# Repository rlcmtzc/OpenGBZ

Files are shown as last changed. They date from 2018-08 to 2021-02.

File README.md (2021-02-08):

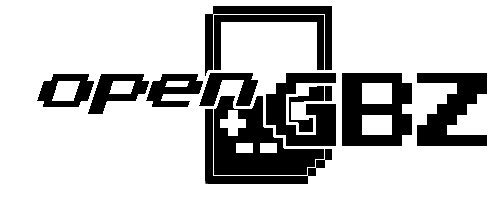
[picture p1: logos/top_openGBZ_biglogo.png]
openGBZ Logo
&emsp;&emsp;&emsp;&emsp;&emsp;&emsp;&emsp;&emsp;&emsp;&emsp;&emsp;
# OpenGBZ
This is an **OpenSource Gameboy Zero PCB Project**. It is intended to make your own custom Button PCB and change the design to your wishes.  
Your welcome to download the PCB files and use it for your own project. If you change anything on the design it would be great if you  
push your changes here so the project can grow and we can get some nice different designs and ideas. Feel also free to push other gameboyzero related PCBs if you want to share them. 

Please also add your changes to the [forum](https://www.sudomod.com/forum/viewtopic.php?f=42&t=6499) post so everybody can easily see the changes and features of the different designs. I will also add the different designes here in the Readme file (Can´t update all the time and immediately so in the forum should be the newest versions and of course in the different directories)  

## How to add your Design and what is needed:
In the different directories you find the different PCBs. If you want to push a design please add a new directory with a name for your designe and in there add a README.md where you can shortly describe the features of your PCB.  

This readme should at least include (See OSDMG0v1 and OSDMG0v2 as a template) :
* **Your name** (and on which board its based of)
* If you tested the Board and if it works
* if you have also a BOM-file for the needed components
* if used in a Build you can link the Build
* A description of the Features of the Board (also some Pictures would be nice)
* Additional Info to the Board if needed. (For example a tutorial how to use specific non self-describing parts pf the boards or also provide software if needed)
* Short description on how to use the board and a list of parts needed for the Board (if not included in the BOM file)  

In the same directory as the readme you should add the .sch and .brd files and gerbers. (You can also link to your project if it was created with an online editor just make sure everybody can get the files)  

You can also add your current work in progress files and ask others for ideas or feedback. If so mark your post as work in progress.  

## Overview of currently added projects:
Here is a short overview of the currently added projets to this repository pleas keep in mind that this part is not necessary up to date pleas look in the forum post or in the different directories for the newest designs.  

| Directory Name | Author Name | Tested | BOM-file | progress |
| :---:|:---:| :---:| :---: | :---:|
| OSDMGBASE | rlcmtzc12 | Yes | not needed| finished |
| OSDMG0v1 | rlcmtzc12 | Yes | Yes | finished |
| OSDMG0v2 | rlcmtzc12 | No | Yes | finished |
| GBPBASE by DerNuntius| DerNuntius | Yes | not needed| finished |
| OSDMG_Leonardo_Shield| rlcmtzc12 (correia5022´s idea)| No | not needed| finished |
## Terms of use
* **You can do everything with the files the only thing I would appreciate is not to use the designs and sell the PCBs this should stay a non-profit project.**
* **Please add the logo found in this directory and add it to your PCB so everybody can determ that this is part of this project**
* **If your design bases of another designe please reference the author**
* **Be sure your files are availible and the readme is present**  

This Project should be for makers who want to create their own projects or just to test something new and this should be a help to getting started. If I see that the terms of use won´t be followed (especially the selling of boards) I´m forced to take down the project or to find another (not that open and easy) way to share the project.  

---  

Feel free to give me feedback/improvements (Best way to get in contact with me is over the [forum](https://www.sudomod.com/forum/memberlist.php?mode=viewprofile&u=9560) just leave a pm)  
Also I´m not a nativ english sepaker so be gracious :D  
I´m looking forward too see your designs

## License
Shield: [][cc-by-sa]

This work is licensed under a
[Creative Commons Attribution-NonCommercial-ShareAlike 4.0 International License][cc-by-sa].

[][cc-by-sa]

[cc-by-sa]: https://creativecommons.org/licenses/by-nc-sa/4.0/
[cc-by-sa-image]: https://i.creativecommons.org/l/by-nc-sa/4.0/88x31.png
[cc-by-sa-shield]: https://img.shields.io/badge/License-CC%20BY--NC--SA%204.0-lightgrey.svg

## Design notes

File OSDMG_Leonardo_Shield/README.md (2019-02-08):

**Author:** rlcmtzc12 *(Based on correia5022 idea)*  
**Tested:** no  
**BOM-file:** not needed   
**Build:** /  

## Description:

This is a Shield like Projekt for the Leonardo/ Pro micro. There is place for a Pro Micro or Leonardo Board and a Battery input and a LED output. It can be also used the same liek the OSDMGBASE Board by just using the throughole pads (Bat and LED of course only works with an Arduino/Leonardo Board).
## Get Project:
The attached Eagle-files include everything.

## Images:

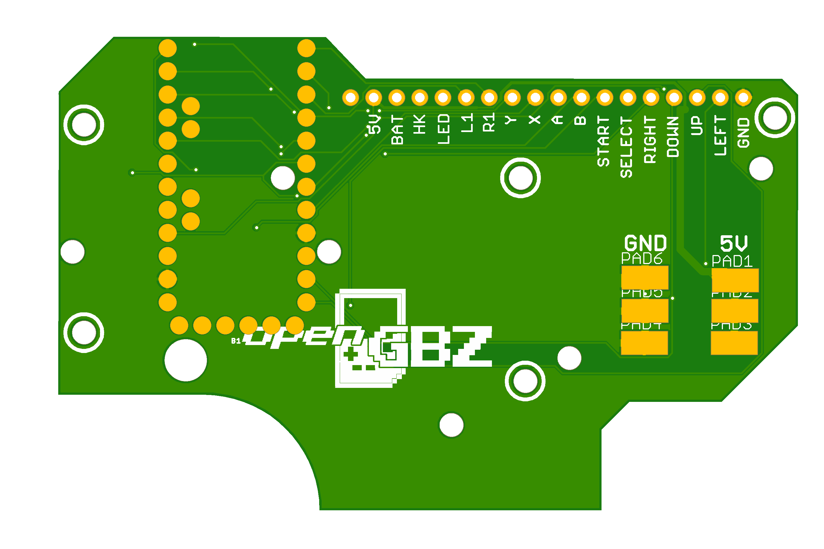
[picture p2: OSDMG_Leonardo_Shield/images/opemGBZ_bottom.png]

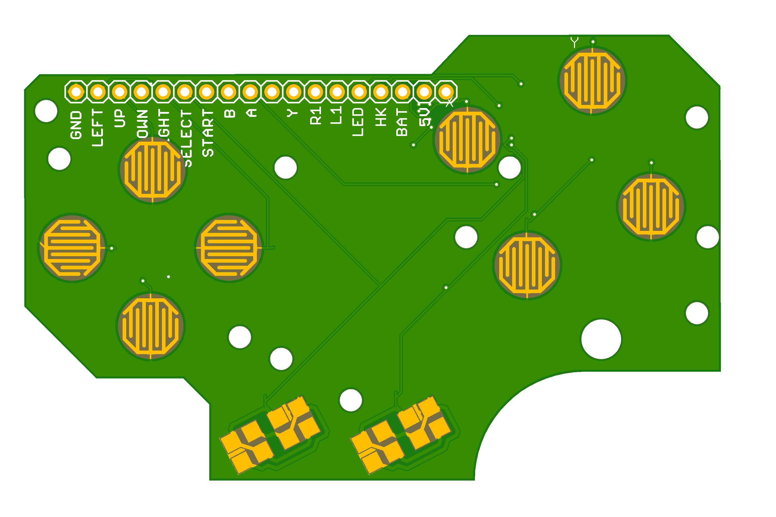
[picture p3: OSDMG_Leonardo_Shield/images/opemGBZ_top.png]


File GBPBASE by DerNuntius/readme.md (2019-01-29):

# First revision of the Gameboy Pocket PCB

**Author:** DerNuntius

**Tested:** Yes

**BOM-file:** unnecessary

**Build:** Later...

## Description:

It's a simple button PCB for the Gameboy Pocket. The PCB is perfect for projects with a Raspberry Pi or an Arduino to create an Arduboy clone.

## Get Project:
[Here](https://github.com/DerNuntius/Gameboy-Zero-Pocket-Button-PCB)

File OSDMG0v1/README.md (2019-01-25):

# First Version of my opensource DMG Board

**Author:** rlcmtzc12 *(Based on rlcmtzc12 design)*  
**Tested:** Yes and working  
**BOM-file:** Included  
**Build:** [Build](https://www.sudomod.com/forum/viewtopic.php?f=43&t=6388)

## Description:

This board has an integrated charging and Boost circuit. The Boost circuit is based on the MT3608 step up IC. (Datasheed found [here](https://www.olimex.com/Products/Breadboarding/BB-PWR-3608/resources/MT3608.pdf)) The outputvoltage is set to around 5.2 Volt. The Boost circuit can be switched on with a powerswitch. I have tested the boostcitcuit with 1,4 A which works fine but the IC gets a little bit warm. I also tested it with 2A which is the max outputcurrent from the Datasheed which works but the IC get really warm so I wouldnd suggest that. On 1 - 1,2A the IC isn´t even warm so it works perfectly fine in this range. The charging circuit of the Battery is based on TP4056 IC which can charge a single lithium-ion battery with up to 1A (Datasheed found [here](https://www.e-gizmo.net/oc/kits%20documents/TP4056-1A%20Li-ion%20Battery%20Charger/TP4056-1A%20Li-ion%20battery%20charger%20Manual.pdf)). Also I integrated the FS312G-F IC which protect the Battery from overcharge, overdischarge and overcurrent (Datasheed found [here](https://www.ic-fortune.com/upload/Download/FS312F-G-DS-12_EN.pdf)). The board will be charged with an usb type c connector. On the board is place for an standard PAM module which then connect to place for a volumewheel and the aux-port. On the front there are the standard buttons (Up, Down, Left, Right, Start, Select, A, B, X, Y)  

## Get Project:
[Here](https://easyeda.com/editor#id=|1b6bda1489604f5b8086fe82ce4b43ba|fd54b8f932f541aa9ddfa8aae15e51a3) you can edit and change the Project online. There are also the Altium and Eagle files.
## Images:




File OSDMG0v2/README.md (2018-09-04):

# Second Version of my opensource DMG Board

**Author:** rlcmtzc12 *(Based on rlcmtzc12 design)*  
**Tested:** Not yet  
**BOM-file:** Not yet   
**Build:** /  

## Description:

This board has an integrated charging and Boost circuit. The Boost circuit is based on the TPS61236P Boost IC. (Datasheed found [here](http://www.ti.com/lit/ds/symlink/tps61236p.pdf)) The outputvoltage is set to around 5 Volt. The Boost circuit can be switched on with a powerswitch. The charging circuit of the Battery is based on TP4056 IC which can charge a single lithium-ion battery with up to 1A (Datasheed found [here](https://www.e-gizmo.net/oc/kits%20documents/TP4056-1A%20Li-ion%20Battery%20Charger/TP4056-1A%20Li-ion%20battery%20charger%20Manual.pdf)). Also I integrated the FS312G-F IC which protect the Battery from overcharge, overdischarge and overcurrent (Datasheed found [here](https://www.ic-fortune.com/upload/Download/FS312F-G-DS-12_EN.pdf)). The board will be charged with an usb type c connector. On the board is place for an standard PAM module which then connect to place for a volumewheel and the aux-port. On the front there are the standard buttons (Up, Down, Left, Right, Start, Select, A, B, X, Y) All the Buttons are connected with an ATmega32u4. The Atmega32u4 can be programmed over the USB-C Port by switching a Button. The Code for the Arduino can be used from the [sudomod wiki](https://www.sudomod.com/wiki/index.php/Leonardo_/_Pro_Micro).
The difference to the first version is that this one has an integrated safe shutdown which is completely done on the hardwareside so you don´t need any script.
It works like following:  
First when you switch on the power a capacitor gets charged. When the capacitor is charged over a given treshold voltage a Mosfet switches on and allow voltage to the pi the capacitor charges on to 5V.
The capacitor is charged in a few miliseconds so there is no delay to turn the raspberry pi on. Next when you turn the switch off a transistor turns an pin to ground this pin is connected to the reset pin of
the pi so when this pin is set to ground the pi turns off. At the same time the capasitor slowly discharges over an resistor when the capacitor is under the thresholdvoltage the Mosfet turns off and so cut the power to the pi.
From turn off until the Mosfet cuts the power pass 15s with this resistor, this is enough time that the pi can shutdown. You also can change the Time by increasing/decreasing the resistor size/ capacitor size. So you only have to
connect a wire to the reset pin off the pi for this safeshutdown to work.

Some Simulationdata of the Boost IC:  
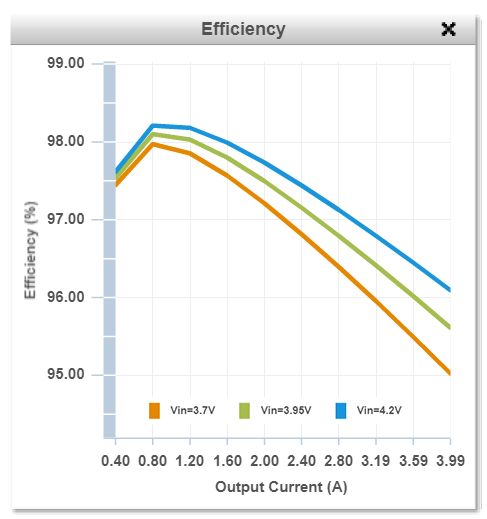
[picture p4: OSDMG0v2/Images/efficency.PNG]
  
(Keep in mind there is also heat, a lot of heat at 4A so you probably should not use it over 3A. I try to make the copperareas on the PCB quit big so they can work as heat sinks but of course they will not dissipate 5V@4A --> 20W)

Here are the Schematics. I splitted them in Eagle up for better overview:
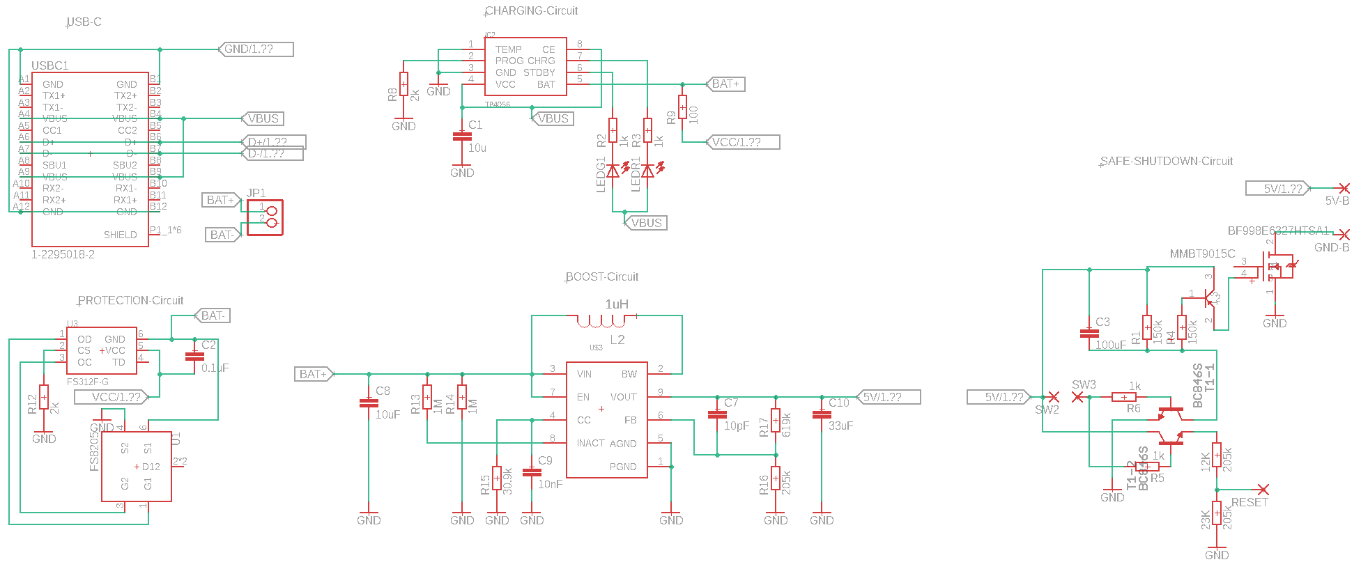
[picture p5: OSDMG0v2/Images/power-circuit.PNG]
  
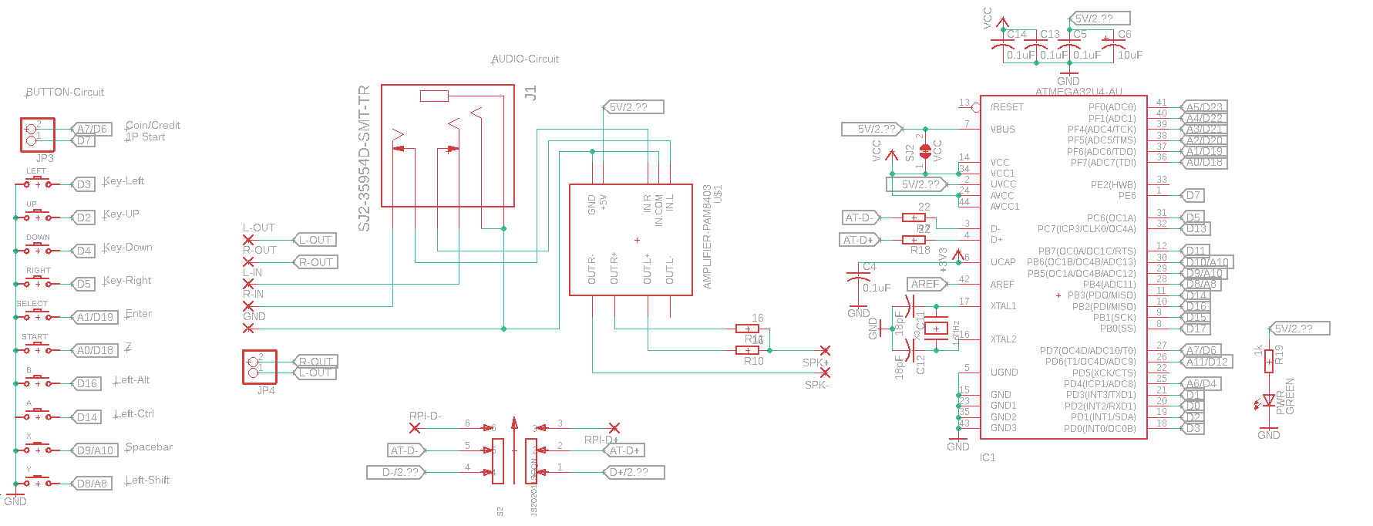
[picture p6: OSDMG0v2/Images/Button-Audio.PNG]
  

The finished PCB (The nameplacement could be done better):
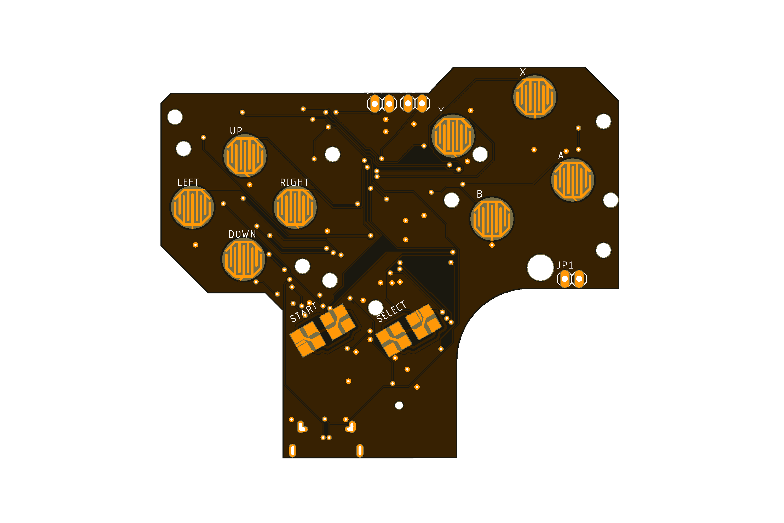
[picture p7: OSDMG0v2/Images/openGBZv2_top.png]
  
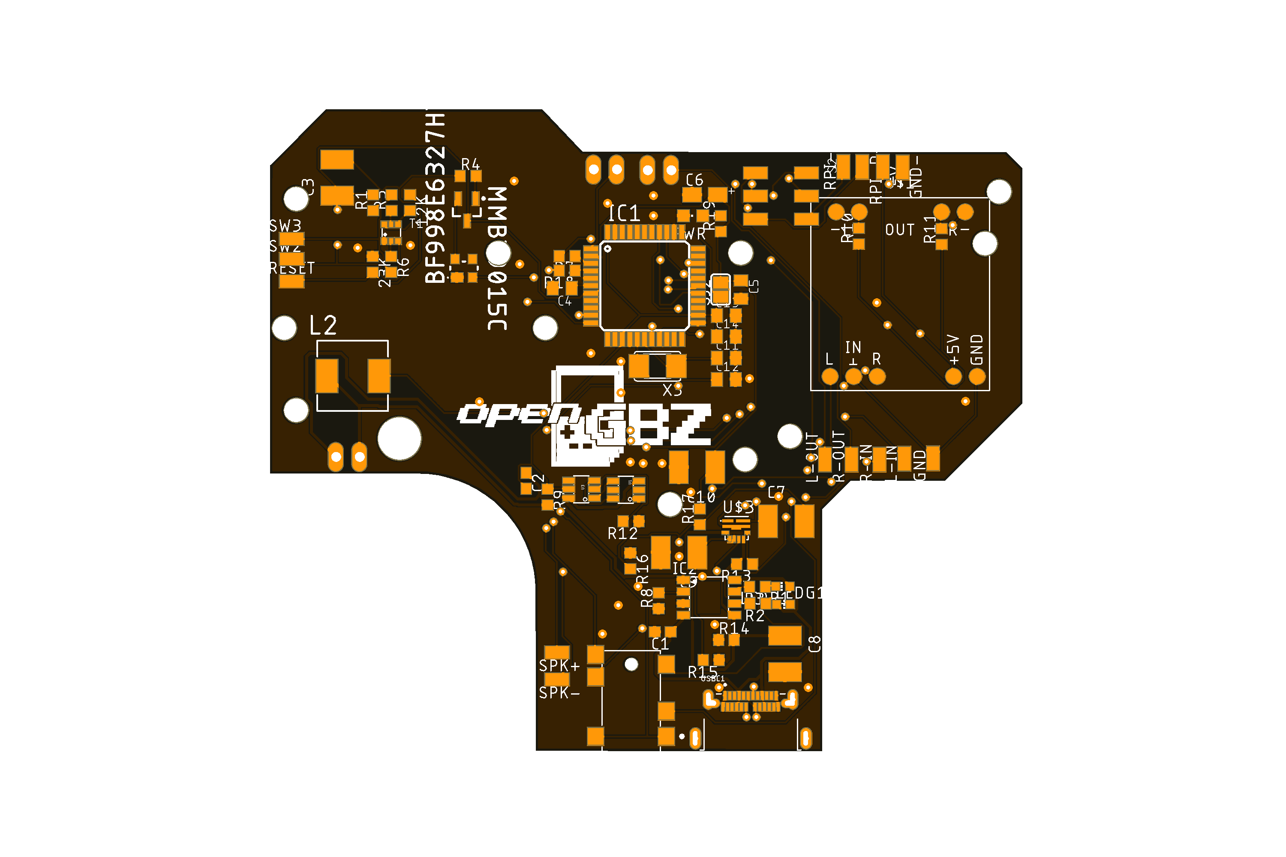
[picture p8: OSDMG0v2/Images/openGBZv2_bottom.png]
  

## Get Project:
Just download the Eagle files.

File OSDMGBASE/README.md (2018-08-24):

# Base Version of my opensource DMG Board

**Author:** rlcmtzc12 *(Based on rlcmtzc12 design)*  
**Tested:** yes  
**BOM-file:** not needed   
**Build:** /  

## Description:

This is the Base Project. The other Projhects I made are based on this one. It only includes a normal button PCB with a common ground and the normal dimensions of the gameboy. This is a good startingpoint for all other projects.

## Get Project:
The attached Eagle-files include everything.

## Images:

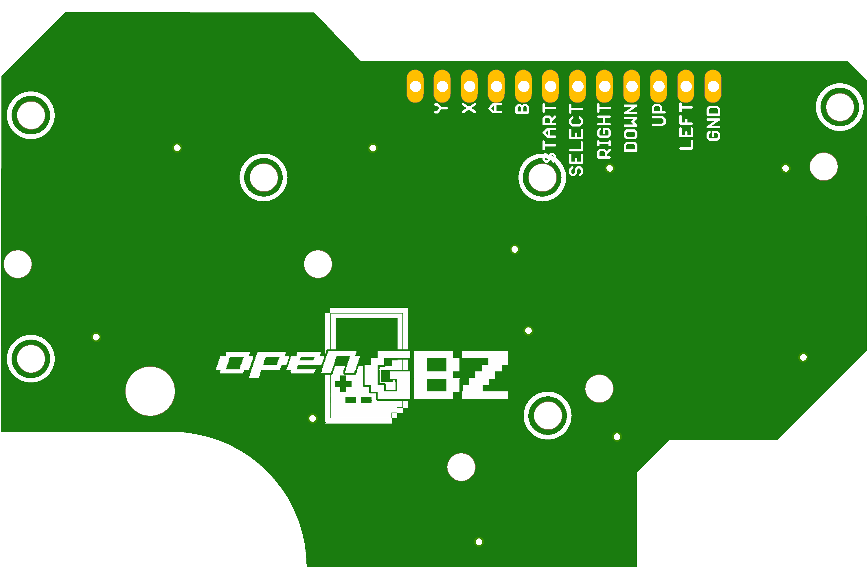
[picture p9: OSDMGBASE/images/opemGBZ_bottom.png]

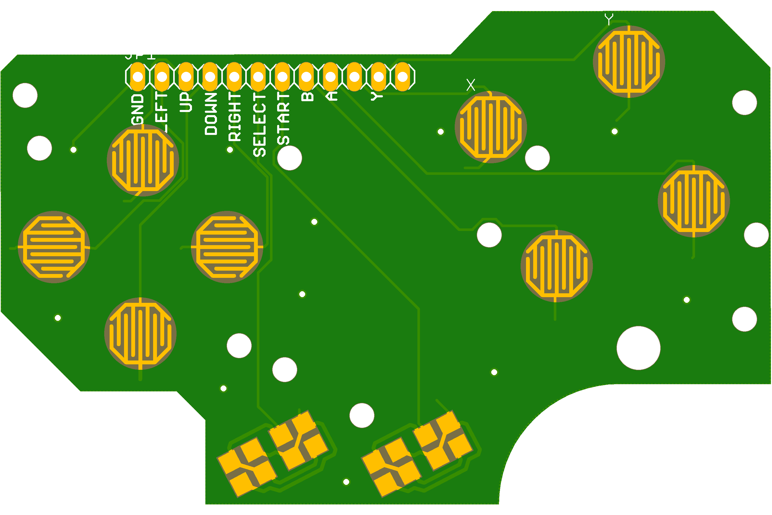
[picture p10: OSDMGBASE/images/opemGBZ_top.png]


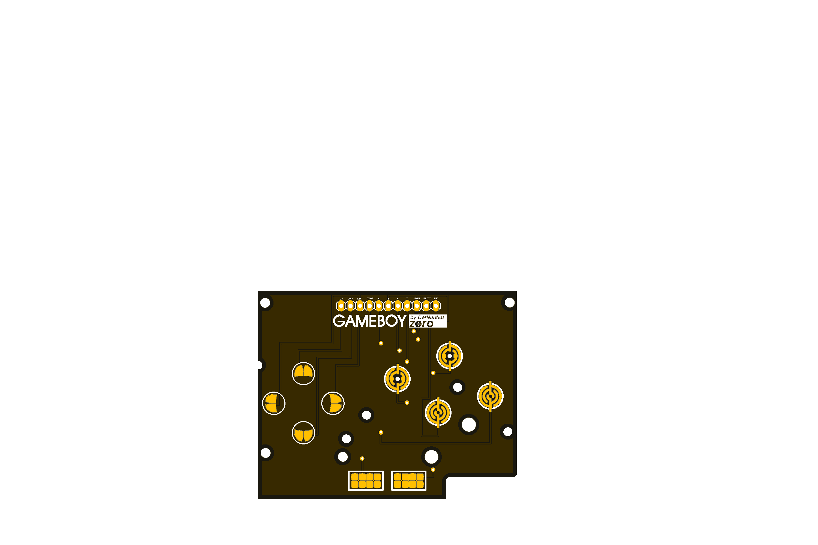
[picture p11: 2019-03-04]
GBPBASE by DerNuntius/images/top.png

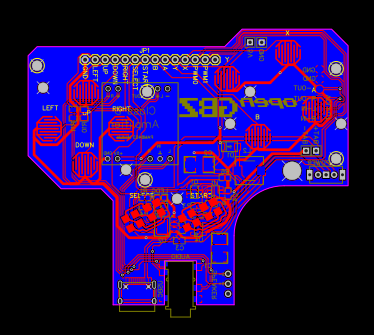
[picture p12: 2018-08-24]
OSDMG0v1/images/PCB_GBA-DMG_20180824161547.png

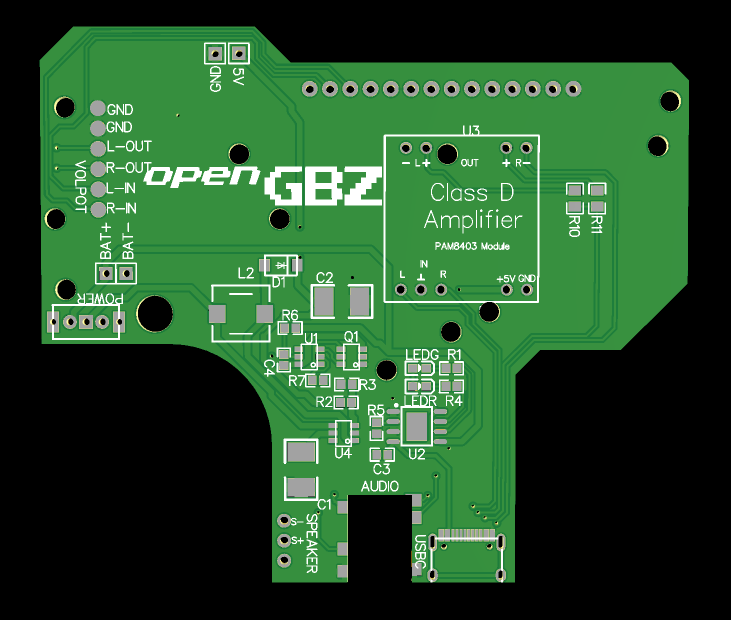
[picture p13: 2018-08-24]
OSDMG0v1/images/bottom_new.PNG

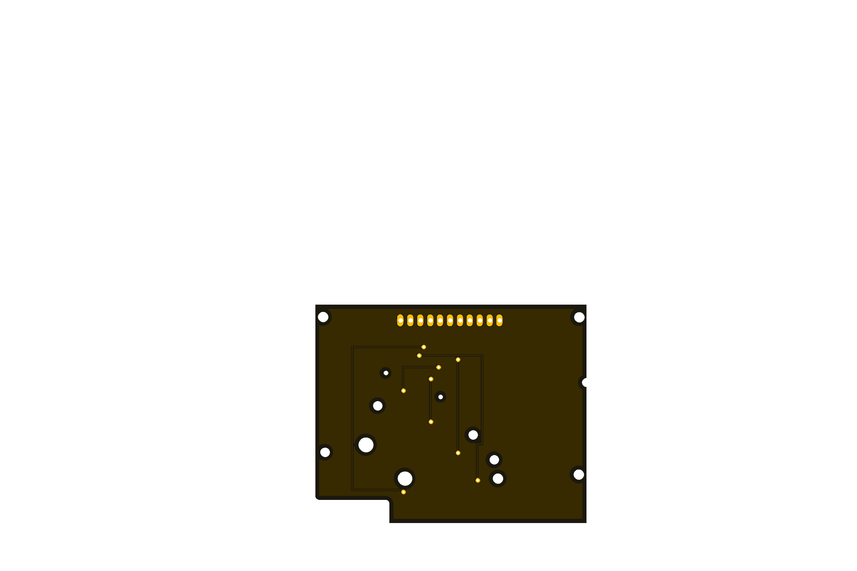
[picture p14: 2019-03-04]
GBPBASE by DerNuntius/images/bottom.png

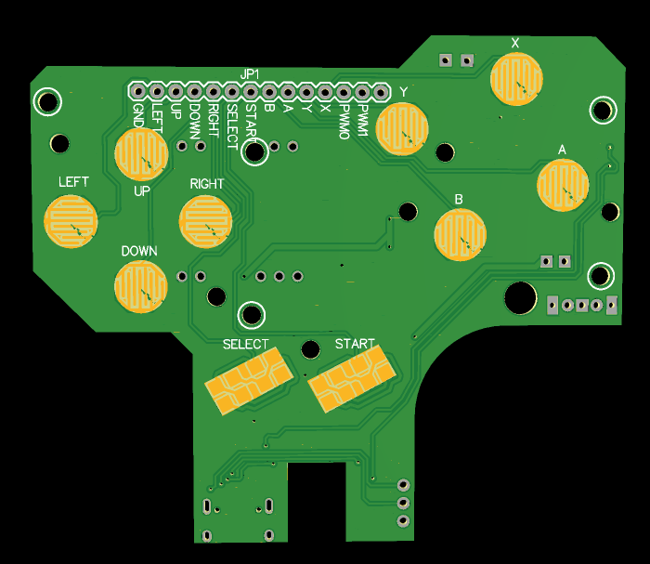
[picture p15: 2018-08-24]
OSDMG0v1/images/top_new.PNG

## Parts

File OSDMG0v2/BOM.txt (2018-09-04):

Bauteil         Wert               Device             Package                   Description                                                           
5V-B                               WIREPADSMD1,27-254 SMD1,27-2,54              Wire PAD connect wire on PCB                                          
12K             205k               R-EU_R0603         R0603                     RESISTOR, European symbol                                             
23K             205k               R-EU_R0603         R0603                     RESISTOR, European symbol                                             
A               DMG-BTN            DMG-BTNREGULAR     DMG-BTN                                                                                         
B               DMG-BTN            DMG-BTNREGULAR     DMG-BTN                                                                                         
BF998E6327HTSA1 INF-SOT143-4-1_V_1 INF-SOT143-4-1_V_1 INF-SOT143-4-1_V_1PRIMARY                                                                       
C1              10u                C-EUC0603          C0603                     CAPACITOR, European symbol                                            
C2              0.1uF              C-EUC0603          C0603                     CAPACITOR, European symbol                                            
C3              100uF              C-EUC1812          C1812                     CAPACITOR, European symbol                                            
C4              0.1uF              C-USC0805K         C0805K                    CAPACITOR, American symbol                                            
C5              0.1uF              C-USC0805K         C0805K                    CAPACITOR, American symbol                                            
C6              10uF               CPOL-USA/3216-18R  A/3216-18R                POLARIZED CAPACITOR, American symbol                                  
C7              10pF               C-EUC1812          C1812                     CAPACITOR, European symbol                                            
C8              10uF               C-EUC1812          C1812                     CAPACITOR, European symbol                                            
C9              10nF               C-EUC1812          C1812                     CAPACITOR, European symbol                                            
C10             33uF               C-EUC1812          C1812                     CAPACITOR, European symbol                                            
C11             18pF               C-USC0805K         C0805K                    CAPACITOR, American symbol                                            
C12             18pF               C-USC0805K         C0805K                    CAPACITOR, American symbol                                            
C13             0.1uF              C-USC0805K         C0805K                    CAPACITOR, American symbol                                            
C14             0.1uF              C-USC0805K         C0805K                    CAPACITOR, American symbol                                            
DOWN            DMG-BTN            DMG-BTNREGULAR     DMG-BTN                                                                                         
GND                                WIREPADSMD1,27-254 SMD1,27-2,54              Wire PAD connect wire on PCB                                          
GND-B                              WIREPADSMD1,27-254 SMD1,27-2,54              Wire PAD connect wire on PCB                                          
IC1             ATMEGA32U4-AU      ATMEGA32U4-AU      TQFP44                                                                                          
IC2             TP4056             TP4056             SOP-8                                                                                           
J1              SJ2-35954D-SMT-TR  SJ2-35954D-SMT-TR  CUI_SJ2-35954D-SMT-TR     4 conductors, 3.5mm, SMT Audio Jack w/ 2 Switch                       
JP1                                PINHD-1X2          1X02                      PIN HEADER                                                            
JP3                                PINHD-1X2          1X02                      PIN HEADER                                                            
JP4                                PINHD-1X2          1X02                      PIN HEADER                                                            
L-IN                               WIREPADSMD1,27-254 SMD1,27-2,54              Wire PAD connect wire on PCB                                          
L-OUT                              WIREPADSMD1,27-254 SMD1,27-2,54              Wire PAD connect wire on PCB                                          
L2              1uH                DR74-220-R         INDM7676X435N             POWER INDUCTOR                                                        
LEDG1                              LEDCHIP-LED0603    CHIP-LED0603              LED                                                                   
LEDR1                              LEDCHIP-LED0603    CHIP-LED0603              LED                                                                   
LEFT            DMG-BTN            DMG-BTNREGULAR     DMG-BTN                                                                                         
MMBT9015C       INF-SOT23_M_1      INF-SOT23_M_1      INF-SOT23_M_1PRIMARY                                                                            
PWR             GREEN              LEDCHIPLED_0805    CHIPLED_0805              LED                                                                   
R-IN                               WIREPADSMD1,27-254 SMD1,27-2,54              Wire PAD connect wire on PCB                                          
R-OUT                              WIREPADSMD1,27-254 SMD1,27-2,54              Wire PAD connect wire on PCB                                          
R1              150k               R-EU_R0603         R0603                     RESISTOR, European symbol                                             
R2              1k                 R-EU_R0603         R0603                     RESISTOR, European symbol                                             
R3              1k                 R-EU_R0603         R0603                     RESISTOR, European symbol                                             
R4              150k               R-EU_R0603         R0603                     RESISTOR, European symbol                                             
R5              1k                 R-EU_R0603         R0603                     RESISTOR, European symbol                                             
R6              1k                 R-EU_R0603         R0603                     RESISTOR, European symbol                                             
R7              22                 R-EU_R0603         R0603                     RESISTOR, European symbol                                             
R8              2k                 R-EU_R0603         R0603                     RESISTOR, European symbol                                             
R9              100                R-EU_R0603         R0603                     RESISTOR, European symbol                                             
R10             16                 R-EU_R0603         R0603                     RESISTOR, European symbol                                             
R11             16                 R-EU_R0603         R0603                     RESISTOR, European symbol                                             
R12             2k                 R-EU_R0603         R0603                     RESISTOR, European symbol                                             
R13             1M                 R-EU_R0603         R0603                     RESISTOR, European symbol                                             
R14             1M                 R-EU_R0603         R0603                     RESISTOR, European symbol                                             
R15             30.9k              R-EU_R0603         R0603                     RESISTOR, European symbol                                             
R16             205k               R-EU_R0603         R0603                     RESISTOR, European symbol                                             
R17             619k               R-EU_R0603         R0603                     RESISTOR, European symbol                                             
R18             22                 R-EU_R0603         R0603                     RESISTOR, European symbol                                             
R19             1k                 R-EU_R0603         R0603                     RESISTOR, European symbol                                             
RESET                              WIREPADSMD1,27-254 SMD1,27-2,54              Wire PAD connect wire on PCB                                          
RIGHT           DMG-BTN            DMG-BTNREGULAR     DMG-BTN                                                                                         
RPI-D+                             WIREPADSMD1,27-254 SMD1,27-2,54              Wire PAD connect wire on PCB                                          
RPI-D-                             WIREPADSMD1,27-254 SMD1,27-2,54              Wire PAD connect wire on PCB                                          
S2              JS202011SCQN       JS202011SCQN       SW_JS202011SCQN           JS Series DPDT On-On Gull Wing Surface Mount Subminiature Slide Switch
SELECT          DMG-BTN            DMG-BTNSELECT      DMG-SEL                                                                                         
SJ2             VCC                SJ                 SJ                        SMD solder JUMPER                                                     
SPK+                               WIREPADSMD1,27-254 SMD1,27-2,54              Wire PAD connect wire on PCB                                          
SPK-                               WIREPADSMD1,27-254 SMD1,27-2,54              Wire PAD connect wire on PCB                                          
START           DMG-BTN            DMG-BTNSELECT      DMG-SEL                                                                                         
SW2                                WIREPADSMD1,27-254 SMD1,27-2,54              Wire PAD connect wire on PCB                                          
SW3                                WIREPADSMD1,27-254 SMD1,27-2,54              Wire PAD connect wire on PCB                                          
T1              BC846S             BC846S             SOT363                    Dual 65 V, 100 mA NPN/NPN general-purpose transistor                  
U$1             AMPLIFIER-PAM8403  AMPLIFIER-PAM8403  AMPLIFIER-PAM8403         Stereo Class-D 3W Audio Amplifier based on PAM8403 chip               
U$3             TPS61235RWLR       CONV_TPS61235RWLR  CONV_TPS61235RWLR                                                                               
U1              FS8205             FS8205             SOT23-6                                                                                         
U3              FS312F-G           FS312F-G           SOT23-6                                                                                         
UP              DMG-BTN            DMG-BTNREGULAR     DMG-BTN                                                                                         
USBC1           1-2295018-2        1-2295018-2        TE_1-2295018-2            SPLASH PROOF USB TYPE C REC, DUAL SMT; Tape/Reel of 900               
X               DMG-BTN            DMG-BTNREGULAR     DMG-BTN                                                                                         
X3              16MHz              XTALNX5032         NX5032                                                                                          
Y               DMG-BTN            DMG-BTNREGULAR     DMG-BTN

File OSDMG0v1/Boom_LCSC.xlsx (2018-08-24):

LCSC Part Number | Manufacture Part Number | Manufacturer | Package | RoHS | Order Qty. | Unit Price | Min\Mult Order Qty. | Order Price
C2286 | KT-0603R | Hubei KENTO Elec | 0603 | No | 50 | $0.0061 | 50\50 | $0.31
C8678 | SS34 | (MDD) Jiangsu Yutai Elec | SMA(DO-214AC) | No | 20 | $0.0307 | 20\20 | $0.61
C14213 | DW01+G | Fortune Semicon | SOT-23-6 | No | 5 | $0.0898 | 5\5 | $0.45
C16581 | TP4056 | Nanjing Extension Microelectronics | SOP-8_EP_150mil | No | 4 | $0.2084 | 1\1 | $0.83
C25286 | 0805W8J0160T5E | Uniroyal Elec | 0805 | Yes | 100 | $0.0032 | 100\100 | $0.32
C27442 | SMRH74-220MT | ShunXiang Connaught Elec | 7*7 | No | 5 | $0.1977 | 1\1 | $0.99
C28504 | 1812X226K250NT | Guangdong Fenghua Advanced Tech | 1812 | Yes | 8 | $0.8176 | 1\1 | $6.54
C32254 | FS8205 | Fortune Semicon | SOT-23-6 | No | 5 | $0.1617 | 1\1 | $0.81
C72043 | 19-217/GHC-YR1S2/3T | Everlight Elec | 0603 | No | 10 | $0.0640 | 10\10 | $0.64
C83061 | 0805F106Z100 | Huaxin S&T | 0805 | No | 10 | $0.0332 | 10\10 | $0.33
C84817 | MT3608 | XI'AN Aerosemi Tech | SOT-23-6 | No | 5 | $0.0675 | 5\5 | $0.34
C103913 | RTT05102JTP | RALEC | 0805 | No | 50 | $0.0024 | 100\100 | $0.12
C115313 | RS-05K202JT | Guangdong Fenghua Advanced Tech | 0805 | No | 100 | $0.0019 | 100\100 | $0.19
C115423 | RS-05K101JT | Guangdong Fenghua Advanced Tech | 0805 | Yes | 100 | $0.0019 | 100\100 | $0.19
C122350 | 0805F104Z500NT | Guangdong Fenghua Advanced Tech | 0805 | No | 10 | $0.0275 | 10\10 | $0.28
C128993 | PJ-399E-6A | Rectangular Connectors - Contacts | Sink plate type | Yes | 5 | $0.2444 | 1\1 | $1.22
C165948 | TYPE-C-31-M-12 | Rectangular Connectors - Contacts | 8.94*7.3mm | No | 6 | $0.3127 | 1\1 | $1.88
C176212 | QR0805J7K5P05 | Ever Ohms Tech | 0805 | No | 100 | $0.0031 | 100\100 | $0.31

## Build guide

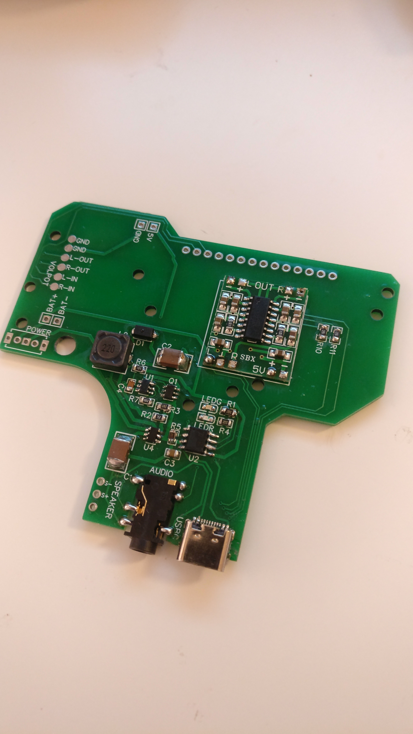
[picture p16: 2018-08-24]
OSDMG0v1/images/pcb_back_soldered.jpg

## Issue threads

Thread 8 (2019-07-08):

OSDMG0v1 PCB components

carjufi, 2019-07-08:
Hi,

How can I know where to place on the PCB the different components? Resistors, etc.

Thanks in advance!

rlcmtzc, 2019-12-06:
Already Answered

Closed 2019-12-06.

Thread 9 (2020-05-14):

Battery charger problem

carjufi, 2020-05-14:
Hello,

I am using this board for my build and I am having power issues. Basically, the GBZ opens and functions normally with power from the battery, but the circuit does not charge it.

I have checked the components and my soldering and I cannot find the problem. When I plug the USB-C I see the red LED, so this tells me the TP4056 is working. For the FS312F, I measure the voltage of OD and OC pins to GND and gives me the current voltage of the battery, I assume that if it gives voltage it is working fine. The last IC is the FS8205 and I have tested it as well and works fine, I thought it was a problem of being inverted when I soldered it, so I changed but nothing powered up. Therefore I solder it back again and the GBZ powers on. I assume then it is working fine.

I really do not understand where is the issue, why it is not charging the battery? Any ideas on how can I check further the components of the circuit?
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

rlcmtzc, 2020-05-17:
Are you sure you did not destroied the fs8205 by reversing it? What battery
are you using?

carjufi <notifications@github.com> schrieb am Do., 14. Mai 2020, 22:33:

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

carjufi, 2020-05-17:
I did change it as well for a new one just in case. The battery I use is a 4000mAh 3.7V LiPo.

rlcmtzc, 2020-05-17:
Ok thats good. Have you meassured the volatge and the currend coming from
the battery port without conecting a battery?

carjufi <notifications@github.com> schrieb am So., 17. Mai 2020, 23:39:

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

carjufi, 2020-05-18:
No, do you mean checking the voltage from GND in the USB-C to BAT+ without battery? I guess I need to check this with the switch on and the USB-C connected, right?
Where do I have to put the multimeters testers to check for the amperage you mention?

Sorry I normally do voltage and continuity checks with the multimeter but never tested the amperage before. As you can see I am no expert in this haha, sorry.

rlcmtzc, 2020-05-23:
No the voltage between the bat+ to bat- wit some kind of loar like a
resistor and the amperege you meassure in series of the bat- connection or
b@t+ connection

carjufi <notifications@github.com> schrieb am Mo., 18. Mai 2020, 17:04:

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

Closed 2021-02-08.

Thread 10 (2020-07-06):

Is the v2 version tested and working?

Giangr, 2020-07-06:
I'm here to ask if the V2 board is working well. Is it? I want to use this build for a test, but I want to know if this is working. Especially the Power boost parts. Thanks!

rlcmtzc, 2020-07-06:
Hi. Its not testet completly.
The poweboost part is working and testet since its the same as in V1 and
there its working fine.

Giangr <notifications@github.com> schrieb am Mo., 6. Juli 2020, 11:42:

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

Giangr, 2020-07-06:
Is it the same? Cause the components are different. And there is a Safe Shutdown in the V2.
Thanks anyway!

rlcmtzc, 2020-07-06:
Yes but the principle. True the safeshutdown is not testet but it can be
left out if not working. This is also only an idea and of the safeshutdown.
I have only tested it seperatly and simulated it in software where it wors
fin but i dont tested it on the board

Giangr <notifications@github.com> schrieb am Mo., 6. Juli 2020, 12:23:

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

Giangr, 2020-07-10:
> Yes but the principle. True the safeshutdown is not testet but it can be left out if not working. This is also only an idea and of the safeshutdown. I have only tested it seperatly and simulated it in software where it wors fin but i dont tested it on the board Giangr <notifications@github.com> schrieb am Mo., 6. Juli 2020, 12:23:
> […](#)
> Is it the same? Cause the components are different. And there is a Safe Shutdown in the V2. Thanks anyway! — You are receiving this because you commented. Reply to this email directly, view it on GitHub <[#10 (comment)](https://github.com/rlcmtzc/OpenGBZ/issues/10#issuecomment-654148857)>, or unsubscribe <https://github.com/notifications/unsubscribe-auth/AKFRURVC266AI354L6LNTVTR2GQYXANCNFSM4ORNW7RA> .

Again, looking quickly at the BOM text, there is a L2 inductor specified as a 22 uH but in the schematic is 1uH. Is the 22uH the one I should consider? Thanks!

rlcmtzc, 2020-07-10:
The 1uH conductor is correct. You can also look up the spcifications of the
parts in the datasheet of the ic. In version two i used a very similar but
better ic for the boost part. Al the charging stayed the same. I tested
this config with the better boost module and it worked fine. I just had no
time lately to include it in v1 of the board

Giangr <notifications@github.com> schrieb am Fr., 10. Juli 2020, 12:37:

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

Giangr, 2020-07-10:
Yes you are right and it's a very good work. Moreover, looking at the datasheet, as you suggested, there is no 10pF cap on the Vout of the boost. Why did you add it? Cause looking at LCSC supplier, it's unavailable (in 1812 package) and it's for 3kv voltage..

Thanks always for the patience!

rlcmtzc, 2020-07-10:
Yes this cap i added to smooth out the output voltage. Its not really
necessary I just thought it wont harm anyway and if there should be a
problem with the boost ic it probably will protect the raspberry a little
bit. You can leave it out or add any cap with around 10pF (more or less
will not change the working of the circuit)

Giangr <notifications@github.com> schrieb am Fr., 10. Juli 2020, 18:04:

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

Closed 2021-03-21.

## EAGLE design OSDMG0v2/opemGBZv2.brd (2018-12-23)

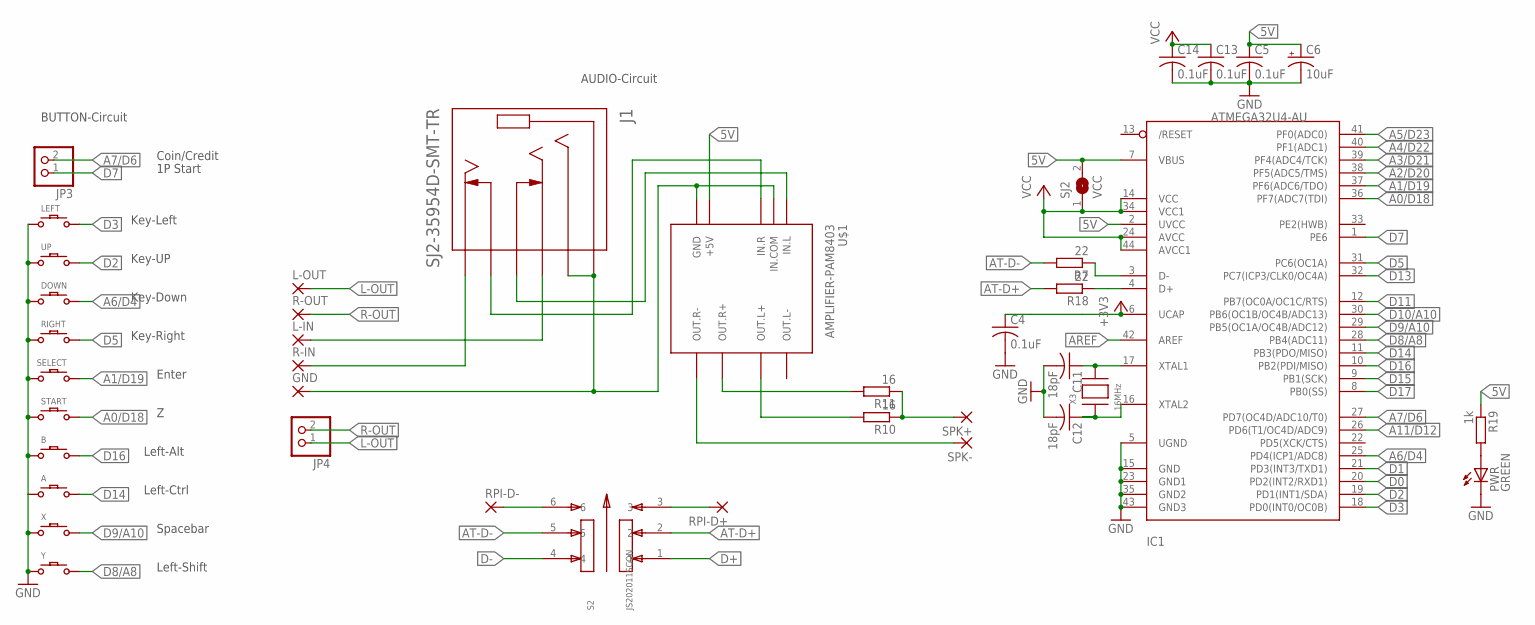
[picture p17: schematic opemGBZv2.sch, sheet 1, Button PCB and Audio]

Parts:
A: DMG-BTN
B: DMG-BTN
C4, C5, C13, C14: 0.1uF; C0805K
C6: 10uF; A/3216-18R
C11, C12: 18pF; C0805K
DOWN: DMG-BTN
GND: WIREPADSMD1,27-254; SMD1,27-2,54
IC1: ATMEGA32U4-AU; TQFP44
J1: SJ2-35954D-SMT-TR; CUI_SJ2-35954D-SMT-TR
JP3, JP4: PINHD-1X2; 1X02
L-IN: WIREPADSMD1,27-254; SMD1,27-2,54
L-OUT: WIREPADSMD1,27-254; SMD1,27-2,54
LEFT: DMG-BTN
PWR: GREEN; CHIPLED_0805
R7, R18: 22; R0603
R10, R11: 16; R0603
R19: 1k; R0603
R-IN: WIREPADSMD1,27-254; SMD1,27-2,54
R-OUT: WIREPADSMD1,27-254; SMD1,27-2,54
RIGHT: DMG-BTN
RPI-D+: WIREPADSMD1,27-254; SMD1,27-2,54
RPI-D-: WIREPADSMD1,27-254; SMD1,27-2,54
S2: JS202011SCQN; SW_JS202011SCQN
SELECT: DMG-BTN; DMG-SEL
SJ2: VCC; SJ
SPK+: WIREPADSMD1,27-254; SMD1,27-2,54
SPK-: WIREPADSMD1,27-254; SMD1,27-2,54
START: DMG-BTN; DMG-SEL
U$1: AMPLIFIER-PAM8403
UP: DMG-BTN
X: DMG-BTN
X3: 16MHz; NX5032
Y: DMG-BTN

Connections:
5V: C5.1, C6.+, IC1.2 (UVCC), IC1.7 (VBUS), R19.1, SJ2.2, U$1.+5V; also elsewhere on the board
+3V3: C4.1, IC1.6 (UCAP)
A0/D18: IC1.36 (PF7(ADC7(TDI)), START.P$1
A1/D19: IC1.37 (PF6(ADC6/TDO)), SELECT.P$1
A2/D20: IC1.38 (PF5(ADC5/TMS))
A3/D21: IC1.39 (PF4(ADC4/TCK))
A4/D22: IC1.40 (PF1(ADC1))
A5/D23: IC1.41 (PF0(ADC0))
A6/D4: DOWN.P$2, IC1.25 (PD4(ICP1/ADC8))
A7/D6: IC1.27 (PD7(OC4D/ADC10/T0)), JP3.2
A11/D12: IC1.26 (PD6(T1/OC4D/ADC9))
AREF: IC1.42 (AREF)
AT-D+: R18.2, S2.2
AT-D-: R7.2, S2.5
D0: IC1.20 (PD2(INT2/RXD1))
D1: IC1.21 (PD3(INT3/TXD1))
D2: IC1.19 (PD1(INT1/SDA)), UP.P$2
D3: IC1.18 (PD0(INT0/OC0B)), LEFT.P$2
D5: IC1.31 (PC6(OC1A)), RIGHT.P$2
D7: IC1.1 (PE6), JP3.1
D8/A8: IC1.28 (PB4(ADC11)), Y.P$2
D9/A10: IC1.29 (PB5(OC1A/OC4B/ADC12)), X.P$2
D10/A10: IC1.30 (PB6(OC1B/OC4B/ADC13))
D11: IC1.12 (PB7(OC0A/OC1C/RTS))
D13: IC1.32 (PC7(ICP3/CLK0/OC4A))
D14: A.P$2, IC1.11 (PB3(PDO/MISO))
D15: IC1.9 (PB1(SCK))
D16: B.P$2, IC1.10 (PB2(PDI/MISO))
D17: IC1.8 (PB0(SS))
D+: S2.1; also elsewhere on the board
D-: S2.4; also elsewhere on the board
GND: A.P$1, B.P$1, C4.2, C5.2, C6.-, C11.2, C12.2, C13.2, C14.2, DOWN.P$1, IC1.5 (UGND), IC1.15 (GND), IC1.23 (GND1), IC1.35 (GND2), IC1.43 (GND3), LEFT.P$1, PWR.C, RIGHT.P$1, SELECT.P$2, START.P$2, UP.P$1, X.P$1, Y.P$1; also elsewhere on the board
L-OUT: JP4.1, L-OUT.1
unnamed: RPI-D-.1, S2.6
unnamed: RPI-D+.1, S2.3
unnamed: R11.2, U$1.OUT.R+
unnamed: GND.1, J1.1 (SLEEVE), J1.4 (RING2), U$1.GND, U$1.IN.COM
unnamed: J1.11 (RING1_SWITCH), U$1.IN.L
unnamed: J1.10 (TIP_SWITCH), U$1.IN.R
unnamed: J1.2 (TIP), R-IN.1
unnamed: J1.3 (RING1), L-IN.1
unnamed: R10.2, U$1.OUT.L+
unnamed: R10.1, R11.1, SPK+.1
unnamed: SPK-.1, U$1.OUT.R-
unnamed: IC1.3 (D-), R7.1
unnamed: IC1.4 (D+), R18.1
unnamed: C12.1, IC1.16 (XTAL2), X3.P$1
unnamed: C11.1, IC1.17 (XTAL1), X3.P$2
unnamed: PWR.A, R19.2
R-OUT: JP4.2, R-OUT.1
VCC: C13.1, C14.1, IC1.14 (VCC), IC1.24 (AVCC), IC1.34 (VCC1), IC1.44 (AVCC1), SJ2.1; also elsewhere on the board

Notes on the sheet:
AUDIO-Circuit
BUTTON-Circuit
Key-UP
Key-Left
Key-Down
Key-Right
Left-Ctrl
Left-Alt
Spacebar
Left-Shift
Enter
Coin/Credit
1P Start

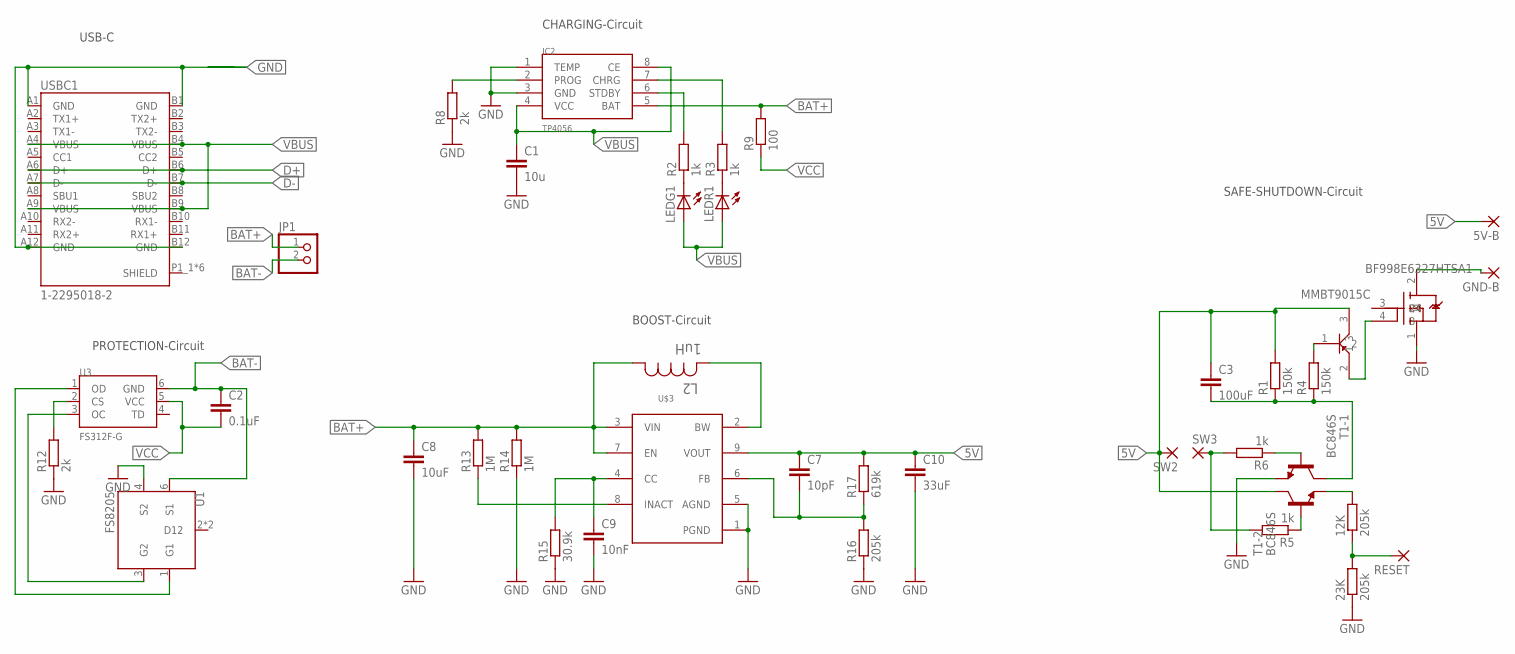
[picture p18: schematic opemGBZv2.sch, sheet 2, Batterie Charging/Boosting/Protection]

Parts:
5V-B: WIREPADSMD1,27-254; SMD1,27-2,54
12K, 23K: 205k; R0603
BF998E6327HTSA1: INF-SOT143-4-1_V_1; INF-SOT143-4-1_V_1PRIMARY
C1: 10u; C0603
C2: 0.1uF; C0603
C3: 100uF; C1812
C7: 10pF; C1812
C8: 10uF; C1812
C9: 10nF; C1812
C10: 33uF; C1812
GND-B: WIREPADSMD1,27-254; SMD1,27-2,54
IC2: TP4056; SOP-8
JP1: PINHD-1X2; 1X02
L2: 1uH; INDM7676X435N
LEDG1: LEDCHIP-LED0603; CHIP-LED0603
LEDR1: LEDCHIP-LED0603; CHIP-LED0603
MMBT9015C: INF-SOT23_M_1; INF-SOT23_M_1PRIMARY
R1, R4: 150k; R0603
R2, R3, R5, R6: 1k; R0603
R8, R12: 2k; R0603
R9: 100; R0603
R13, R14: 1M; R0603
R15: 30.9k; R0603
R16: 205k; R0603
R17: 619k; R0603
RESET: WIREPADSMD1,27-254; SMD1,27-2,54
SW2, SW3: WIREPADSMD1,27-254; SMD1,27-2,54
T1: BC846S; SOT363
U1: FS8205; SOT23-6
U3: FS312F-G; SOT23-6
U$3: TPS61235RWLR; CONV_TPS61235RWLR
USBC1: 1-2295018-2; TE_1-2295018-2

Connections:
5V: 5V-B.1, C3.1, C7.1, C10.1, MMBT9015C.3 (1), R1.2, R17.2, SW2.1, T1.3 (C), U$3.9 (VOUT); also elsewhere on the board
BAT+: C8.1, IC2.5 (BAT), JP1.1, L2.1, R9.2, R13.2, R14.2, U$3.3 (VIN), U$3.7 (EN)
BAT-: C2.1, JP1.2, U1.6 (S1), U3.6 (GND)
D+: USBC1.A6 (D+), USBC1.B6 (D+); also elsewhere on the board
D-: USBC1.A7 (D-), USBC1.B7 (D-); also elsewhere on the board
GND: 23K.1, BF998E6327HTSA1.1 (4), C1.2, C8.2, C9.2, C10.2, IC2.1 (TEMP), IC2.3 (GND), R8.1, R12.1, R14.1, R15.1, R16.1, T1.1 (E), U1.4 (S2), U$3.1 (PGND), U$3.5 (AGND), USBC1.A1 (GND), USBC1.A12 (GND), USBC1.B1 (GND), USBC1.B12 (GND); also elsewhere on the board
unnamed: BF998E6327HTSA1.2 (1), GND-B.1
unnamed: BF998E6327HTSA1.4 (3), MMBT9015C.2 (3)
unnamed: MMBT9015C.1 (2), R4.2
unnamed: 12K.2, T1.4 (E)
unnamed: C3.2, R1.1, R4.1, T1.6 (C)
unnamed: R6.1, T1.2 (B)
unnamed: R5.2, R6.2, SW3.1
unnamed: R5.1, T1.5 (B)
unnamed: R13.1, U$3.8 (INACT)
unnamed: C9.1, R15.2, U$3.4 (CC)
unnamed: IC2.6 (STDBY), R2.2
unnamed: IC2.7 (CHRG), R3.2
unnamed: LEDG1.C, R2.1
unnamed: L2.2, U$3.2 (BW)
unnamed: LEDR1.C, R3.1
unnamed: C7.2, R16.2, R17.1, U$3.6 (FB)
unnamed: IC2.2 (PROG), R8.2
unnamed: U1.3 (G2), U3.3 (OC)
unnamed: U1.1 (G1), U3.1 (OD)
unnamed: R12.2, U3.2 (CS)
unnamed: 12K.1, 23K.2, RESET.1
VBUS: C1.1, IC2.4 (VCC), IC2.8 (CE), LEDG1.A, LEDR1.A, USBC1.A4 (VBUS), USBC1.A9 (VBUS), USBC1.B4 (VBUS), USBC1.B9 (VBUS)
VCC: C2.2, R9.1, U3.5 (VCC); also elsewhere on the board

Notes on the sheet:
BOOST-Circuit
PROTECTION-Circuit
CHARGING-Circuit
SAFE-SHUTDOWN-Circuit
USB-C

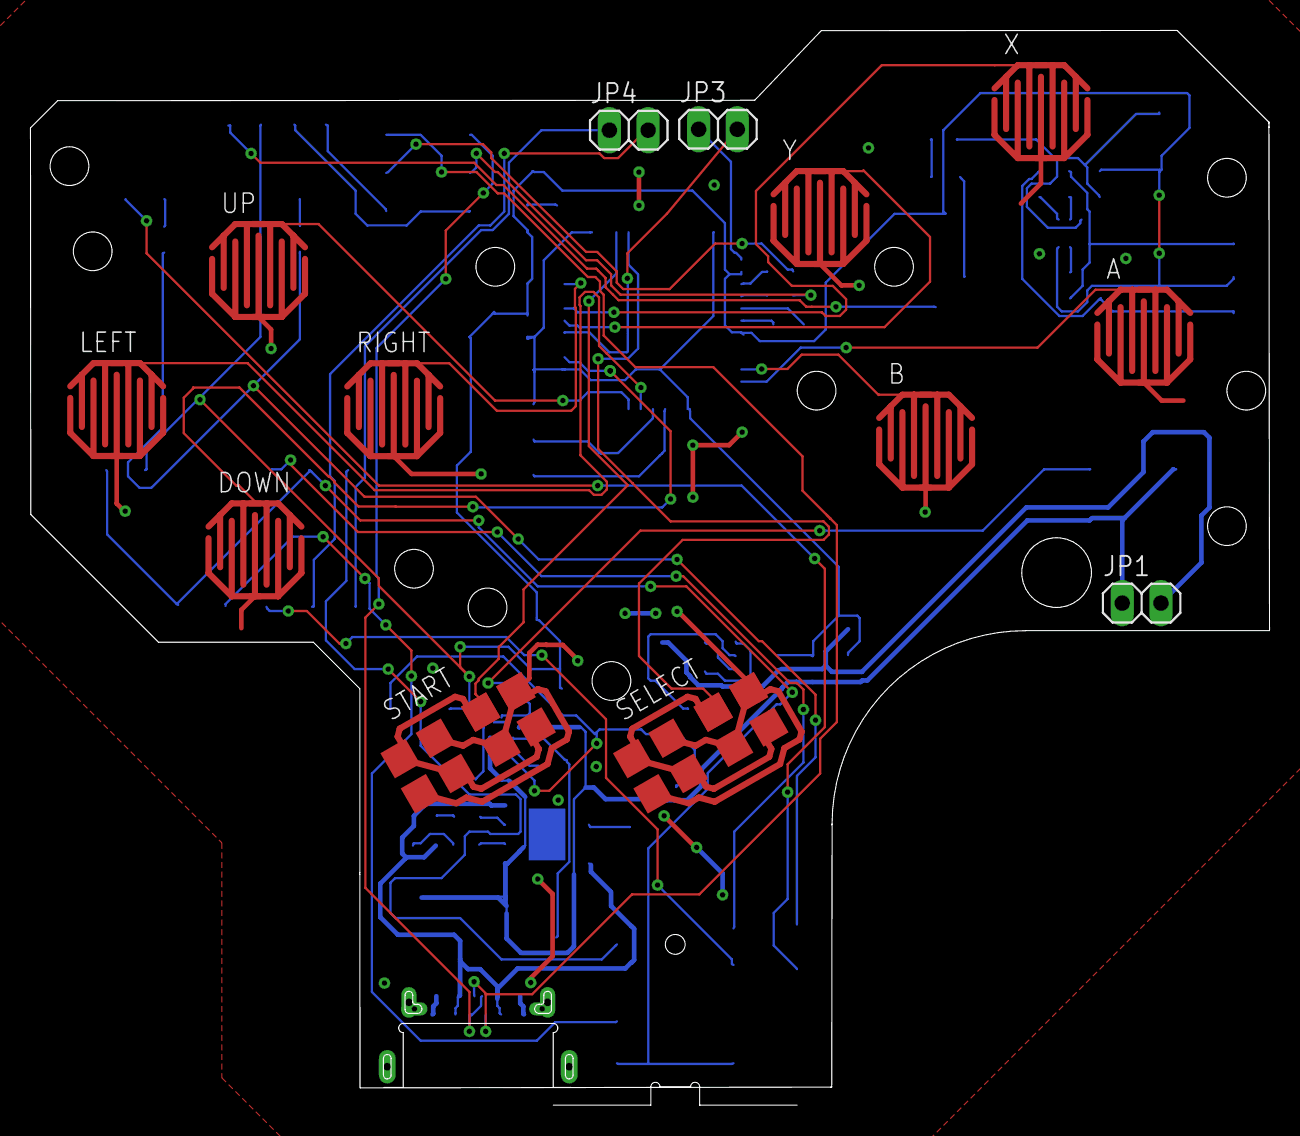
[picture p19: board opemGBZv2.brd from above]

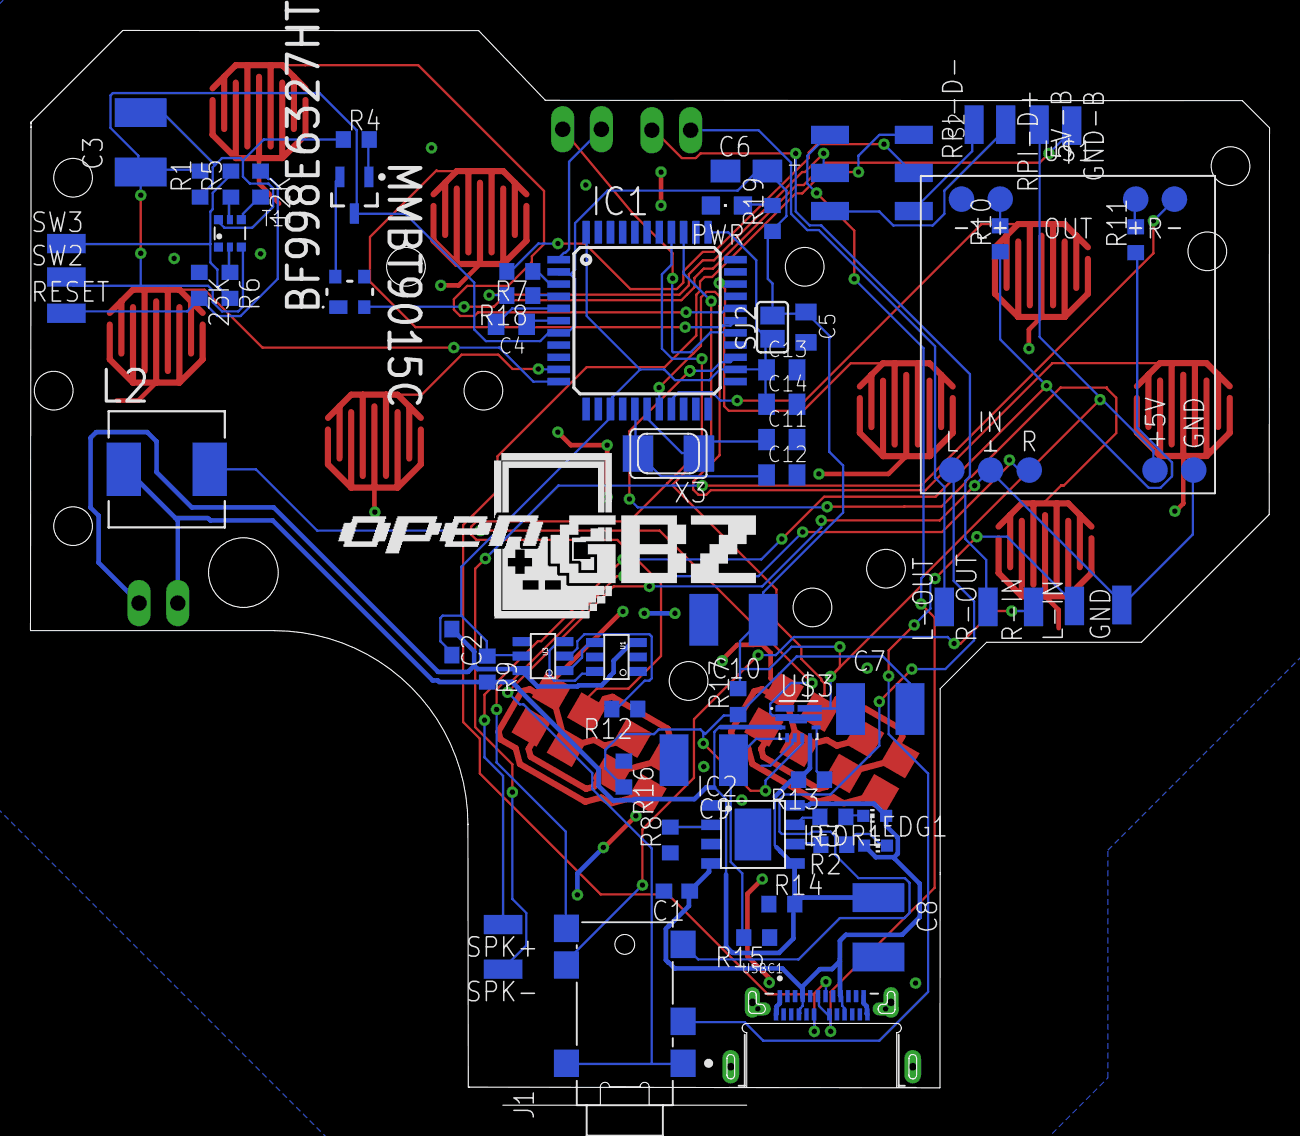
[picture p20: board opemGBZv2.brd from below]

Board: 2 copper layers, 81.3 x 70.5 mm, 80 parts (67 on the bottom side), 62 nets.

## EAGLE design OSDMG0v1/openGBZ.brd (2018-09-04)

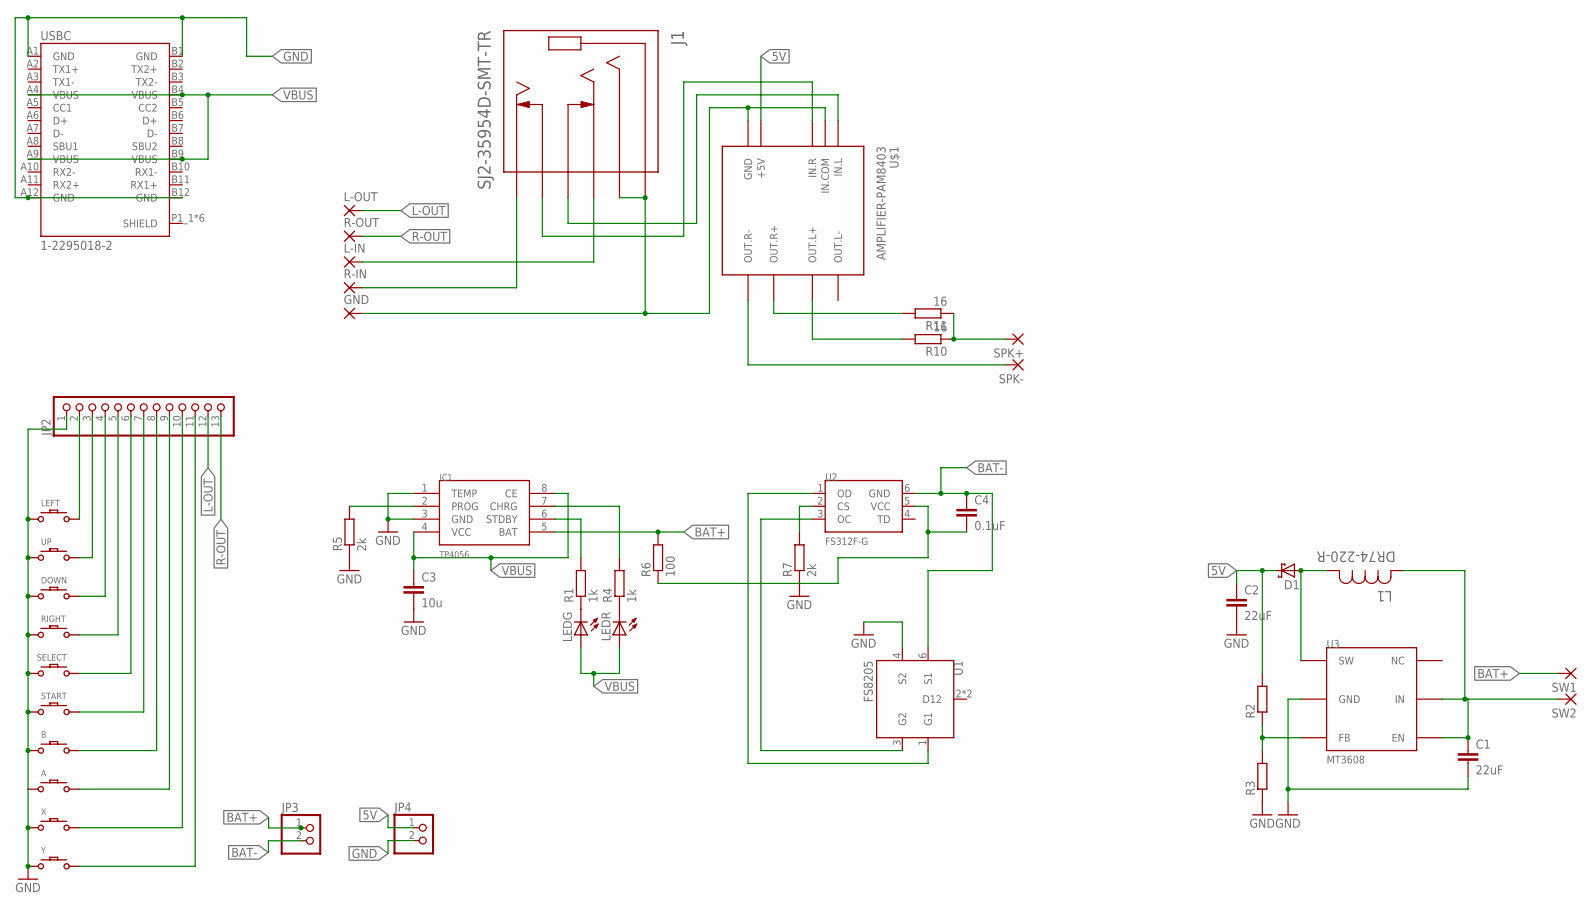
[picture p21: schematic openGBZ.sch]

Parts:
A: DMG-BTN
B: DMG-BTN
C1, C2: 22uF; C1812
C3: 10u; C0603
C4: 0.1uF; C0603
D1: SCHOTTKY-DIODESMD; SMB
DOWN: DMG-BTN
GND: WIREPADSMD1,27-254; SMD1,27-2,54
IC1: TP4056; SOP-8
J1: SJ2-35954D-SMT-TR; CUI_SJ2-35954D-SMT-TR
JP2: PINHD-1X13; 1X13
JP3, JP4: PINHD-1X2; 1X02
L1: DR74-220-R; INDM7676X435N
L-IN: WIREPADSMD1,27-254; SMD1,27-2,54
L-OUT: WIREPADSMD1,27-254; SMD1,27-2,54
LEDG: LEDCHIP-LED0603; CHIP-LED0603
LEDR: LEDCHIP-LED0603; CHIP-LED0603
LEFT: DMG-BTN
R1, R4: 1k; R0603
R2, R3: R-EU_R0603; R0603
R5, R7: 2k; R0603
R6: 100; R0603
R10, R11: 16; R0603
R-IN: WIREPADSMD1,27-254; SMD1,27-2,54
R-OUT: WIREPADSMD1,27-254; SMD1,27-2,54
RIGHT: DMG-BTN
SELECT: DMG-BTN; DMG-SEL
SPK+: WIREPADSMD1,27-254; SMD1,27-2,54
SPK-: WIREPADSMD1,27-254; SMD1,27-2,54
START: DMG-BTN; DMG-SEL
SW1, SW2: WIREPADSMD1,27-254; SMD1,27-2,54
U1: FS8205; SOT23-6
U2: FS312F-G; SOT23-6
U3: MT3608; SOT23-6
U$1: AMPLIFIER-PAM8403
UP: DMG-BTN
USBC: 1-2295018-2; TE_1-2295018-2
X: DMG-BTN
Y: DMG-BTN

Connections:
5V: C2.1, D1.C, JP4.1, R2.2, U$1.+5V
BAT+: IC1.5 (BAT), JP3.1, R6.2, SW1.1
BAT-: C4.1, JP3.2, U1.6 (S1), U2.6 (GND)
GND: A.P$1, B.P$1, C1.2, C2.2, C3.2, DOWN.P$1, IC1.1 (TEMP), IC1.3 (GND), JP2.1, JP4.2, LEFT.P$1, R3.1, R5.1, R7.1, RIGHT.P$1, SELECT.P$2, START.P$2, U1.4 (S2), U3.2 (GND), UP.P$1, USBC.A1 (GND), USBC.A12 (GND), USBC.B1 (GND), USBC.B12 (GND), X.P$1, Y.P$1
L-OUT: JP2.12, L-OUT.1
unnamed: JP2.2, LEFT.P$2
unnamed: JP2.3, UP.P$2
unnamed: DOWN.P$2, JP2.4
unnamed: JP2.5, RIGHT.P$2
unnamed: JP2.6, SELECT.P$1
unnamed: JP2.7, START.P$1
unnamed: B.P$2, JP2.8
unnamed: A.P$2, JP2.9
unnamed: JP2.10, X.P$2
unnamed: JP2.11, Y.P$2
unnamed: IC1.6 (STDBY), R1.2
unnamed: IC1.7 (CHRG), R4.2
unnamed: LEDG.C, R1.1
unnamed: LEDR.C, R4.1
unnamed: IC1.2 (PROG), R5.2
unnamed: U1.3 (G2), U2.3 (OC)
unnamed: U1.1 (G1), U2.1 (OD)
unnamed: R7.2, U2.2 (CS)
unnamed: D1.A, L1.1, U3.1 (SW)
unnamed: R2.1, R3.2, U3.3 (FB)
unnamed: R11.2, U$1.OUT.R+
unnamed: GND.1, J1.1 (SLEEVE), J1.4 (RING2), U$1.GND, U$1.IN.COM
unnamed: J1.11 (RING1_SWITCH), U$1.IN.L
unnamed: J1.10 (TIP_SWITCH), U$1.IN.R
unnamed: J1.2 (TIP), R-IN.1
unnamed: J1.3 (RING1), L-IN.1
unnamed: R10.2, U$1.OUT.L+
unnamed: R10.1, R11.1, SPK+.1
unnamed: SPK-.1, U$1.OUT.R-
unnamed: C4.2, R6.1, U2.5 (VCC)
unnamed: C1.1, L1.2, SW2.1, U3.4 (EN), U3.5 (IN)
R-OUT: JP2.13, R-OUT.1
VBUS: C3.1, IC1.4 (VCC), IC1.8 (CE), LEDG.A, LEDR.A, USBC.A4 (VBUS), USBC.A9 (VBUS), USBC.B4 (VBUS), USBC.B9 (VBUS)

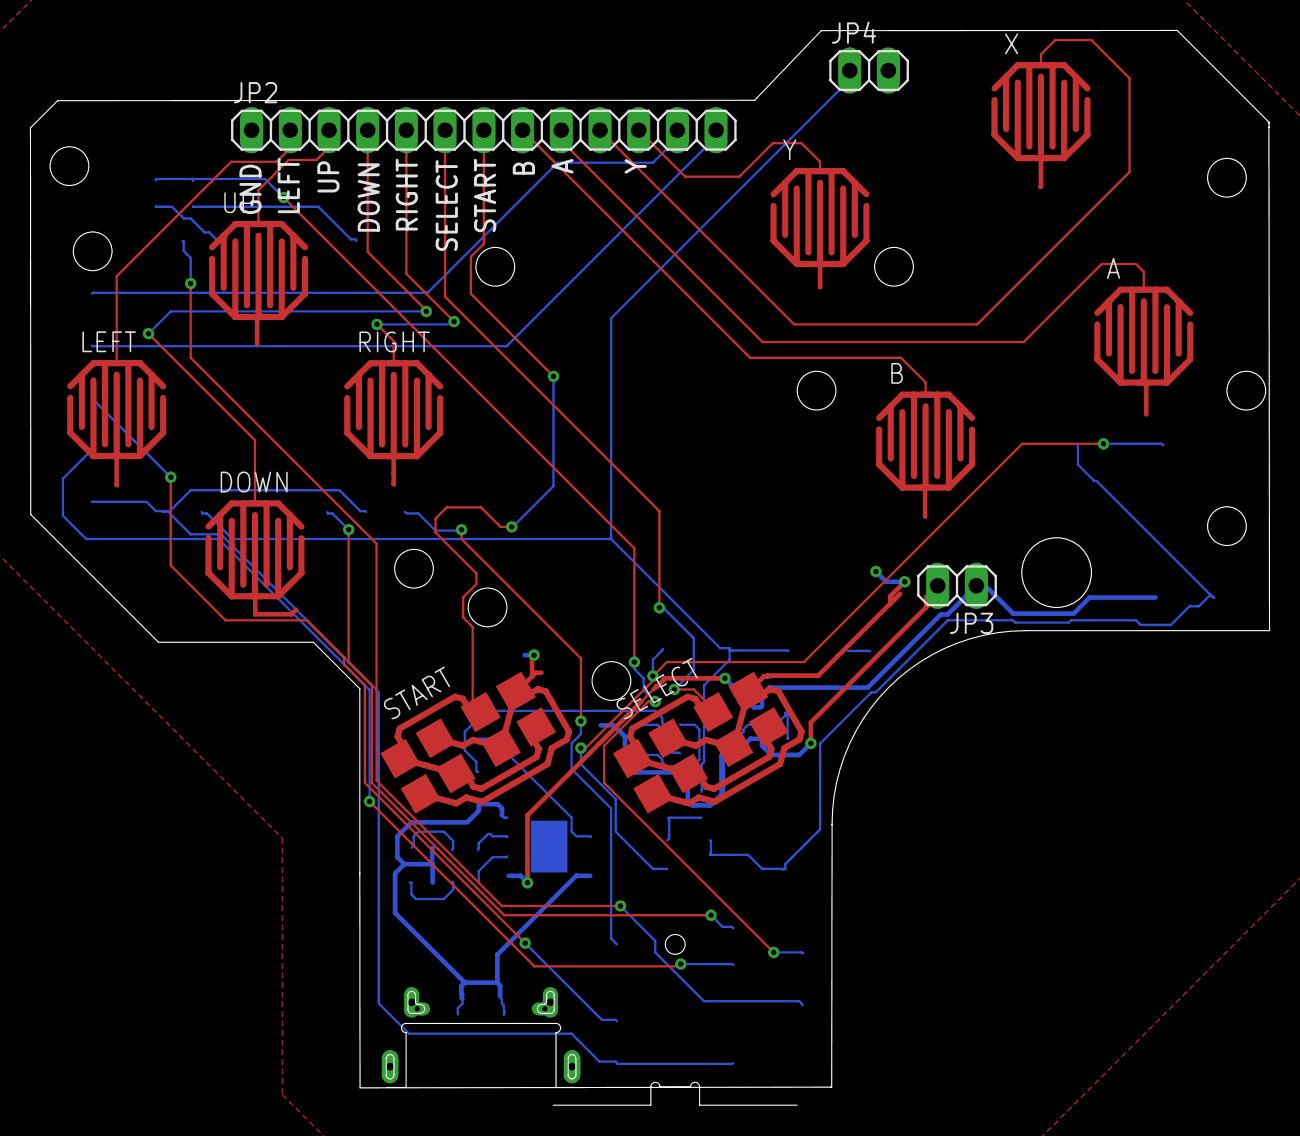
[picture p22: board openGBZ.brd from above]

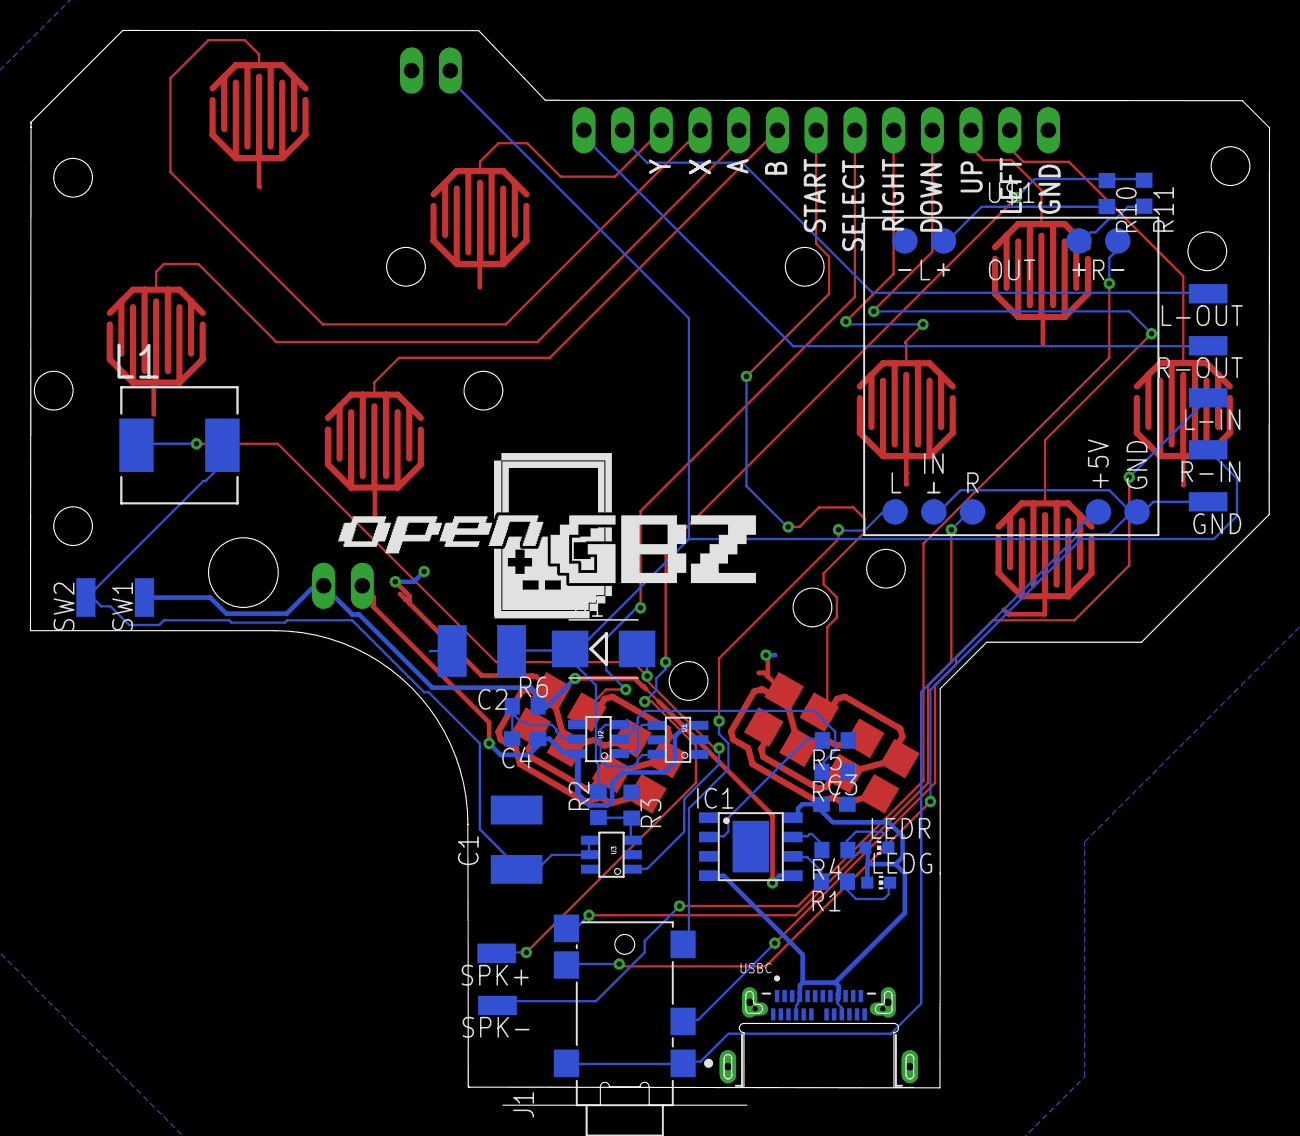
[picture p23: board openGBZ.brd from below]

Board: 2 copper layers, 81.3 x 70.5 mm, 46 parts (33 on the bottom side), 38 nets.

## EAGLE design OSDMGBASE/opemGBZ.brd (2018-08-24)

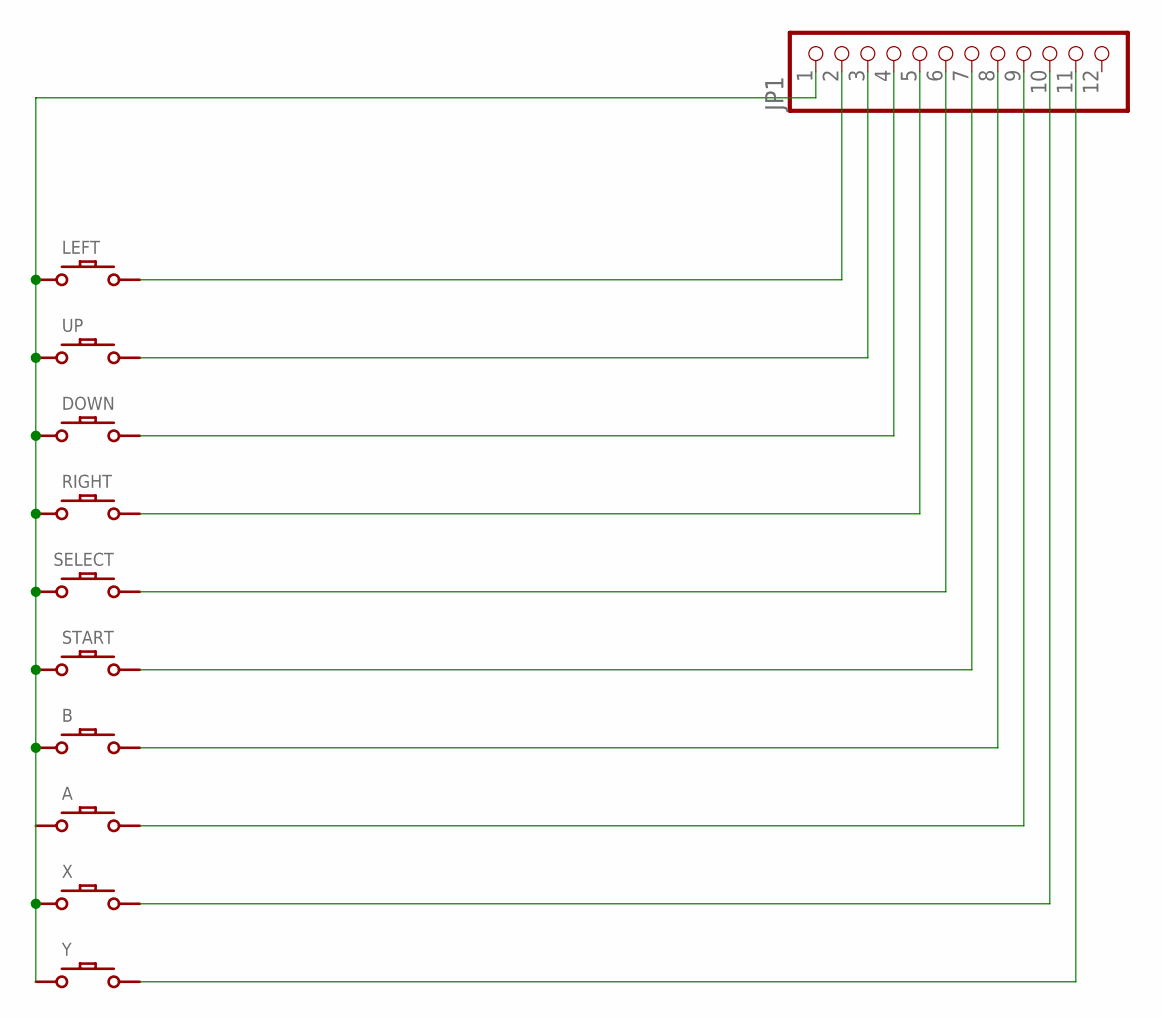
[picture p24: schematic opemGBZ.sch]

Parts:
A: DMG-BTN
B: DMG-BTN
DOWN: DMG-BTN
JP1: PINHD-1X12; 1X12
LEFT: DMG-BTN
RIGHT: DMG-BTN
SELECT: DMG-BTN; DMG-SEL
START: DMG-BTN; DMG-SEL
UP: DMG-BTN
X: DMG-BTN
Y: DMG-BTN

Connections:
GND: A.P$1, B.P$1, DOWN.P$1, JP1.1, LEFT.P$1, RIGHT.P$1, SELECT.P$2, START.P$2, UP.P$1, X.P$1, Y.P$1
unnamed: JP1.2, LEFT.P$2
unnamed: JP1.3, UP.P$2
unnamed: DOWN.P$2, JP1.4
unnamed: JP1.5, RIGHT.P$2
unnamed: JP1.6, SELECT.P$1
unnamed: JP1.7, START.P$1
unnamed: B.P$2, JP1.8
unnamed: A.P$2, JP1.9
unnamed: JP1.10, X.P$2
unnamed: JP1.11, Y.P$2

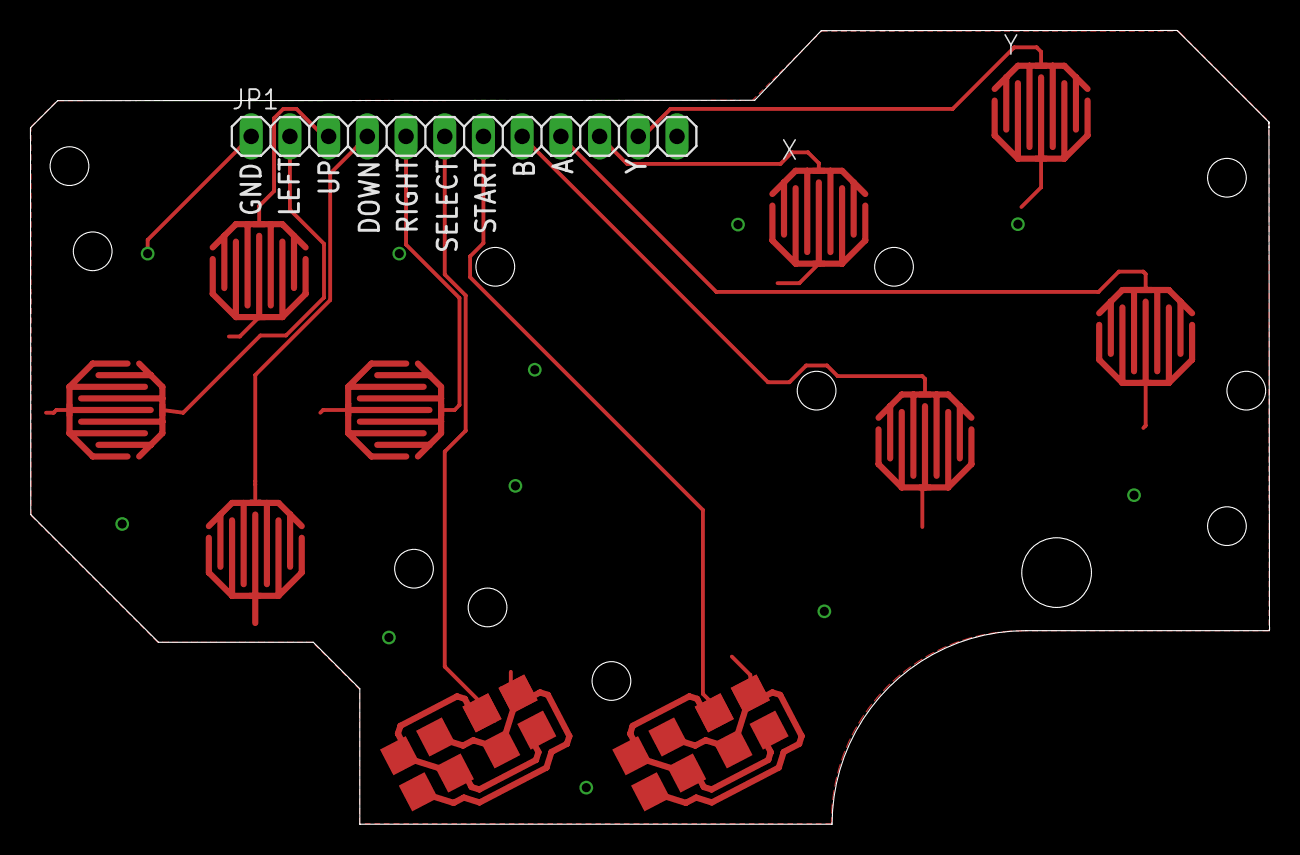
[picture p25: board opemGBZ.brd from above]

Board: 2 copper layers, 81.3 x 52.1 mm, 11 parts (0 on the bottom side), 11 nets.

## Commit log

2018-08-24 base open gbz
    [opemGBZ.brd, opemGBZ.sch]
2018-08-25 Eagle files brd not routed yet
    [opemGBZ.brd, opemGBZ.sch]
2018-08-25 update Eagle
    [opemGBZ.brd, opemGBZ.sch]
2018-08-30 new boost circuit
2018-08-31 update board
    [opemGBZv2.brd, opemGBZv2.sch]
2018-09-01 everything routed up GND
    [opemGBZv2.brd, opemGBZv2.sch]
2018-09-04 Eagle finished
    [opemGBZ.brd, opemGBZ.sch]
2018-09-04 update and finish all projects
    [openGBZ.brd, openGBZ.sch, openGBZv2.brd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]
2018-09-04 Bom file
2018-12-23 Add files via upload
    Error fix
    [opemGBZv2.brd, opemGBZv2.sch]
2019-01-25 Adding GBP Base
    [gameboypocket.brd, gameboypocket.sch]
2019-01-26 update new project
    update new project
    [GBZLNDShield.brd, GBZLNDShield.sch]
2019-01-28 Second Revision
    - NEW Buttons
    - NEW Design
    [gameboypocket.brd, gameboypocket.sch]
2019-01-29 Minor Changes
    [base.brd, base.sch]
2019-01-31 update board
    5V and GND Pads and better placement of the leonardo
    [GBZLNDShield.brd, GBZLNDShield.sch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]
2019-03-02 Drill FIX
    [base.brd]
2019-03-02 Revision 2 Minor Fixes
    [base.brd]
2019-03-03 Release V2
    [base.brd, base.sch]

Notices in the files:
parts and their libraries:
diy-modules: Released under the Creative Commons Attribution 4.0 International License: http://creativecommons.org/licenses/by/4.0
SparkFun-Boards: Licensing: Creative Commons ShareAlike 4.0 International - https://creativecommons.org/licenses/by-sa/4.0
